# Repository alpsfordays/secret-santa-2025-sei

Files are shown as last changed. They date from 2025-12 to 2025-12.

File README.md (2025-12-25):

# Secret Santa 2025 : Sei
This repo holds all the files for my secret santa gift, *La Carte Blanche*; a card-sized 14-key keyboard with PG1316S and M switches running FAK on a CH552T.

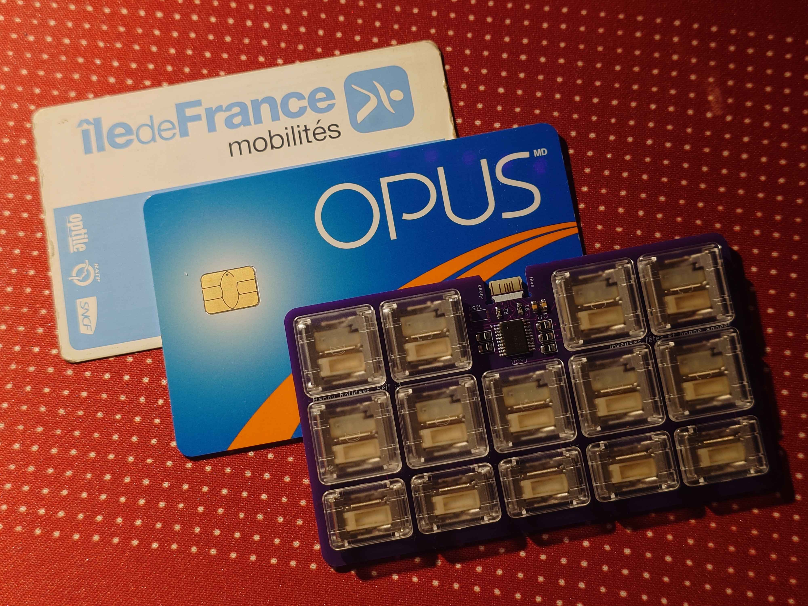
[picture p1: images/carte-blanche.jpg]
une carte blanche assemblée


## PCB
All the PCB files and [gerbers](pcb/secret-santa-2025/jlcpcb/gerber/) are available; the PCB can be assembled with 14 0805 1N4148 diodes, 2 0605 100nF capacitors, 2 0605 5.1K resistors and a CH55T. You will need 9 PG1316S and 5 PG1316M switches.
For the min-spec USB-C connector, I recommend having the PCB made with ENIG plating to increase durability. It will need to be 0.8mm thick (0.6mm works too but would be a little loose). 
The reset button is available [here](https://www.lcsc.com/product-detail/C963197.html) from LCSC.

## Firmware
Put the [carte-blanche](firmware/carte-blanche/) folder into the keyboards folder of your fak-config and compile.  The [.ihx](firmware/carte-blanche.ihx) is also included if you would like to test your PCB; the base layout is alphabetical from left to right, top down.

## Credits and Licensing
Credit to [AnasMalas](https://github.com/AnasMalas/pcb-edge-usb-c) for the min-spec USB-C connector. The silk was drawn by me with technical drawings created from STEP files made available by Kailh.
The USB-C connector is under a CC-1.0 licence, and the project proper is under the [CERN-OHL-S-2.0 licence](LICENSE).

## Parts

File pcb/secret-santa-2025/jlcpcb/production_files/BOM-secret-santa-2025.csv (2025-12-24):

Comment | Designator | Footprint | LCSC | Quantity
D_45deg | D6 | D_0805_2012Metric |  | 1
~ | SW13 | PG1316M_0.7U_castellated |  | 1
~ | SW11 | PG1316M_0.7U_castellated |  | 1
D_45deg | D10 | D_0805_2012Metric |  | 1
D_45deg | D7 | D_0805_2012Metric |  | 1
~ | SW2 | PG1316S_1U_castellated |  | 1
~ | SW5 | PG1316S_1U_castellated |  | 1
D_45deg | D5 | D_0805_2012Metric |  | 1
D_45deg | D4 | D_0805_2012Metric |  | 1
~ | SW4 | PG1316S_1U_castellated |  | 1
D_45deg | D9 | D_0805_2012Metric |  | 1
D_45deg | D1 | D_0805_2012Metric |  | 1
D_45deg | D13 | D_0805_2012Metric |  | 1
D_45deg | D2 | D_0805_2012Metric |  | 1
0.1µF | C2 | C_0603_1608Metric |  | 1
RESET | RST1 | GT-TC024 |  | 1
D_45deg | D3 | D_0805_2012Metric |  | 1
5.1K | R2 | C_0603_1608Metric |  | 1
~ | SW10 | PG1316M_0.7U_castellated |  | 1
D_45deg | D14 | D_0805_2012Metric |  | 1
D_45deg | D8 | D_0805_2012Metric |  | 1
5.1K | R1 | C_0603_1608Metric |  | 1
~ | SW1 | PG1316S_1U_castellated |  | 1
D_45deg | D11 | D_0805_2012Metric |  | 1
~ | SW14 | PG1316M_0.7U_castellated |  | 1
D_45deg | D12 | D_0805_2012Metric |  | 1
~ | SW6 | PG1316S_1U_castellated |  | 1
~ | SW9 | PG1316S_1U_castellated |  | 1
~ | SW7 | PG1316S_1U_castellated |  | 1
~ | SW3 | PG1316S_1U_castellated |  | 1
0.1µF | C1 | C_0603_1608Metric |  | 1
CH552T | U1 | TSSOP-20_4.4x6.5mm_P0.65mm |  | 1
~ | SW8 | PG1316S_1U_castellated |  | 1
~ | SW12 | PG1316M_0.7U_castellated |  | 1

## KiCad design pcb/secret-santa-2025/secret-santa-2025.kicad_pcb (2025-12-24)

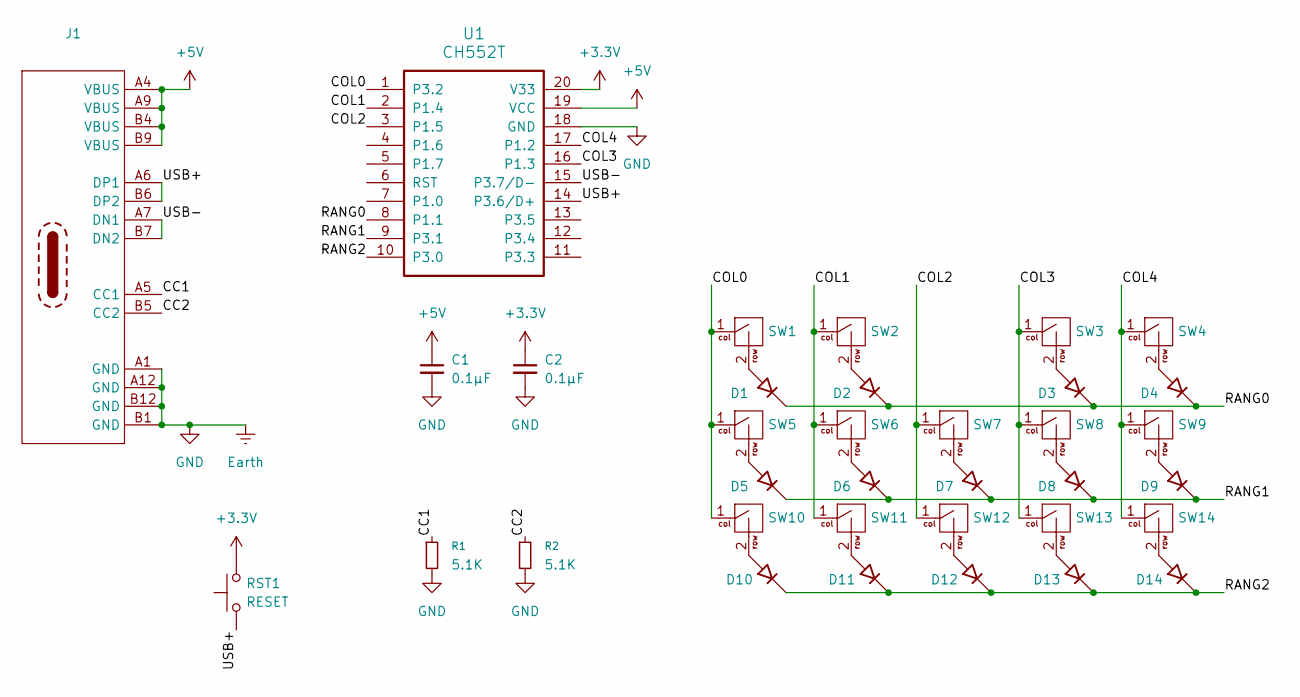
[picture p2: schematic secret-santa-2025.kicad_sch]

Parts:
C1, C2: 0.1µF; C_0603_1608Metric
D1, D2, D3, D4, D5, D6, D7, D8, D9, D10, D11, D12, D13, D14: D_45deg; D_0805_2012Metric
J1: PCBTypeC_14P
R1, R2: 5.1K; C_0603_1608Metric
RST1: RESET; GT-TC024
SW1, SW2, SW3, SW4, SW5, SW6, SW7, SW8, SW9: PG1316S_1U_castellated
SW10, SW11, SW12, SW13, SW14: PG1316M_0.7U_castellated
U1: CH552T; TSSOP-20_4.4x6.5mm_P0.65mm

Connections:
+3.3V: C2.1, RST1.2, U1.20 (V33)
+5V: C1.1, J1.A4 (VBUS), J1.A9 (VBUS), J1.B4 (VBUS), J1.B9 (VBUS), U1.19 (VCC)
/CC1: J1.A5 (CC1), R1.1
/CC2: J1.B5 (CC2), R2.1
/COL0: SW1.1, SW5.1, SW10.1, U1.1 (P3.2)
/COL1: SW2.1, SW6.1, SW11.1, U1.2 (P1.4)
/COL2: SW7.1, SW12.1, U1.3 (P1.5)
/COL3: SW3.1, SW8.1, SW13.1, U1.16 (P1.3)
/COL4: SW4.1, SW9.1, SW14.1, U1.17 (P1.2)
/RANG0: D1.1 (K), D2.1 (K), D3.1 (K), D4.1 (K), U1.8 (P1.1)
/RANG1: D5.1 (K), D6.1 (K), D7.1 (K), D8.1 (K), D9.1 (K), U1.9 (P3.1)
/RANG2: D10.1 (K), D11.1 (K), D12.1 (K), D13.1 (K), D14.1 (K), U1.10 (P3.0)
/USB+: J1.A6 (DP1), J1.B6 (DP2), RST1.1, U1.14 (P3.6/D+)
/USB-: J1.A7 (DN1), J1.B7 (DN2), U1.15 (P3.7/D-)
Earth: C1.2, C2.2, J1.A1 (GND), J1.A12 (GND), J1.B1 (GND), J1.B12 (GND), R1.2, R2.2, U1.18 (GND)
unnamed: D1.2 (A), SW1.2
unnamed: D2.2 (A), SW2.2
unnamed: D3.2 (A), SW3.2
unnamed: D4.2 (A), SW4.2
unnamed: D5.2 (A), SW5.2
unnamed: D6.2 (A), SW6.2
unnamed: D7.2 (A), SW7.2
unnamed: D8.2 (A), SW8.2
unnamed: D9.2 (A), SW9.2
unnamed: D10.2 (A), SW10.2
unnamed: D11.2 (A), SW11.2
unnamed: D12.2 (A), SW12.2
unnamed: D13.2 (A), SW13.2
unnamed: D14.2 (A), SW14.2

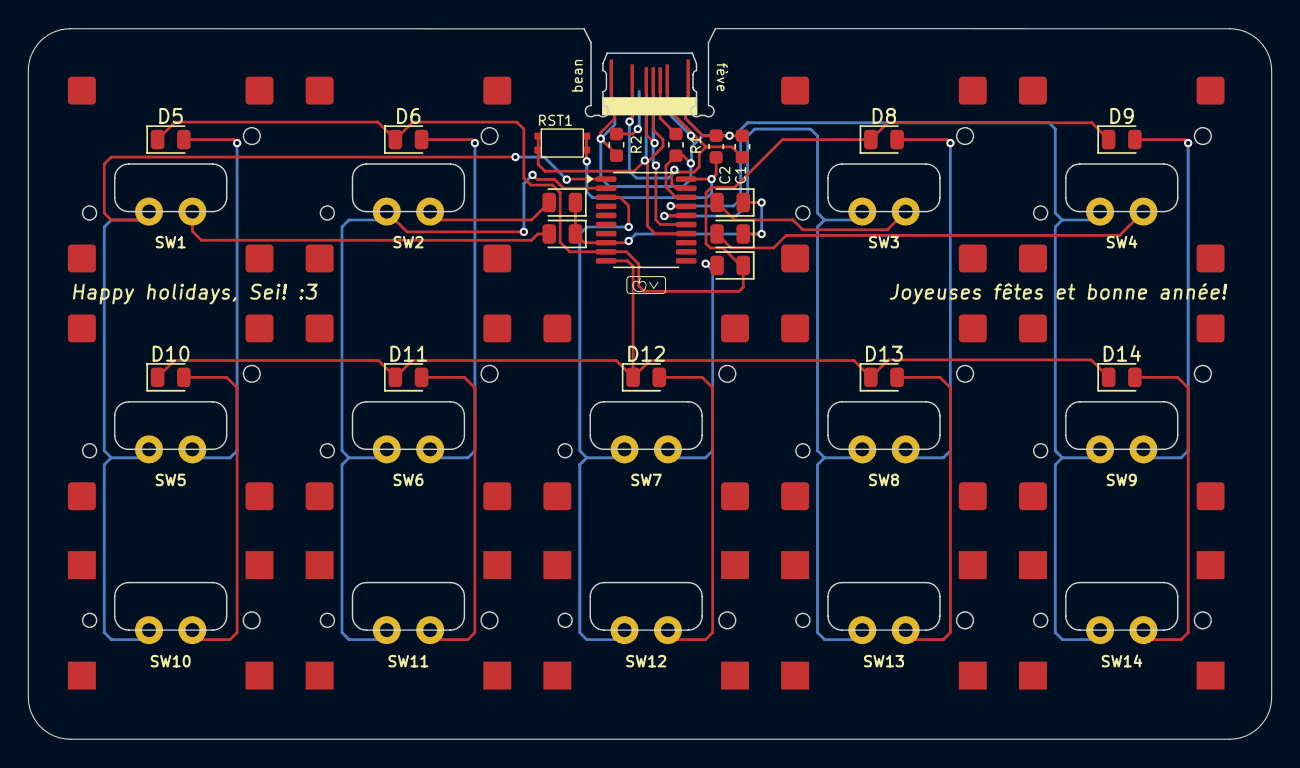
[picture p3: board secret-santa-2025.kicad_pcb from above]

Board: 2 copper layers, 88.9 x 50.8 mm, 35 parts (0 on the bottom side), 29 nets.
